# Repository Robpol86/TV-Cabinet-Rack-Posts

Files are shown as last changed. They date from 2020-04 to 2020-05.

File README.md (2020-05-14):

# TV Cabinet Rack Posts

3D printable rack posts with square holes for a Majestic EX 70-inch TV stand (Standout Designs).

* Cabinet dimensions (mm): **500** (W) x **460** (H) x **538** (D)
* Holes front offset: **112**
* Holes rear offset: **102**
* Top corner clearance with screw: **4.95**
* Door width: **20**
* Center of square hole distance: **465**

## Protocase Notes and Design Constraints

> TODO: Apply .05" fillets to corners.

### Material

> TODO: Increase to 3 mm.

304 Stainless Steel (A240 TP304 2B) 14 Gauge (**1.981 mm**)

### Colors

[Proto-Stock Matt Black, Low Gloss, Smooth Hybrid](https://www.protocase.com/img/products/mcf/powdercoat/matte-black-proto-stock.jpg)

### Bend Radius

https://www.protocase.com/resources/bend-radius.php

Category        |           Thickness | Minimum Bend | Bend Radius
--------------- | ------------------: | ------------:| ----------:
Stainless Steel | 14 Gauge (1.981 mm) |      6.98 mm |      1.9 mm

### K-Factor

> TODO: Derive k-factor from changed bend radius in eDrawing file sent by Protocase for v0.1.

* **0.440**

## Cura Settings

This is for a **Monoprice Maker Select 3D Printer v2** configured as a **Prusa i3** printer in Cura.

* Profile: **0.2**
* Infill: **20%**
* Infill Pattern: **Octet**
* Build Plate Adhesion: **Skirt**
* Skirt Distance: **6 mm**
* Support Placement: **Touching Buildplate**
* Support Overhang Angle: **50**
* Support Horizontal Expansion: **2**
* *Add support blocker to the rack holes*

## Planned Use

This section is to determine if the depth of the rack is sufficient in the short term.

   U | Current      | Future L      | Future R
---: | ------------ | ------------- | -------------
   1 | Patch Panel  | Patch Panel   | Patch Panel
   2 | Switch       | Switch        | Switch
   3 |              | pfSense + RPi | pfSense + RPi
   4 |              | SAN + Worker  | SAN + Worker
   5 |              | SAN + Worker  | SAN + Worker
   6 | pfSense + FS |               | GPU + Worker
   7 | pfSense + FS |               | GPU + Worker
   8 | Drawer       | Drawer        |
   9 | UPS          | UPS           | UPS
  10 | UPS          | UPS           | UPS

### Depths

* Posts (inner): **461 mm**
* Protocase Rails (C2907-18): **457 mm**
* Travla Rails: *2 inches too long, will sit on shelf*
* Drawer: **348 mm**
* UPS: *No depth because the rails won't fit. Will sit on the bottom.*

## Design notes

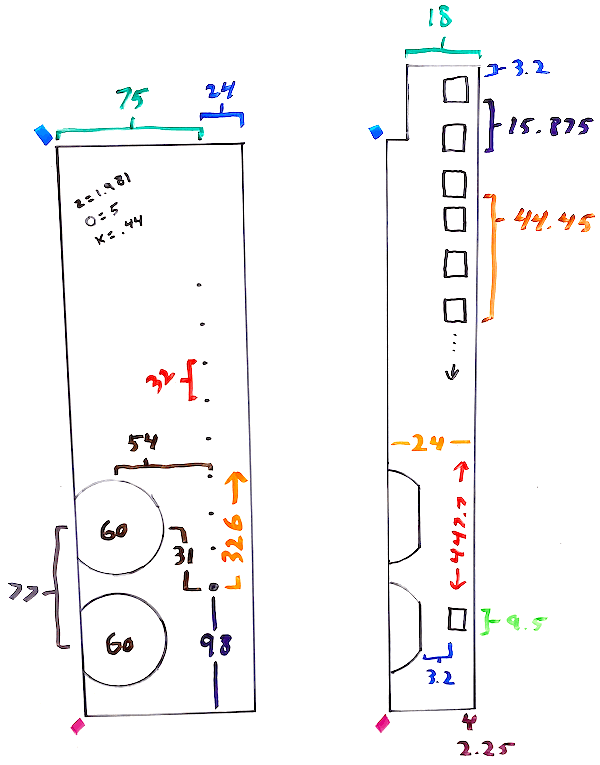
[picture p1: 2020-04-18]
blueprint.gif

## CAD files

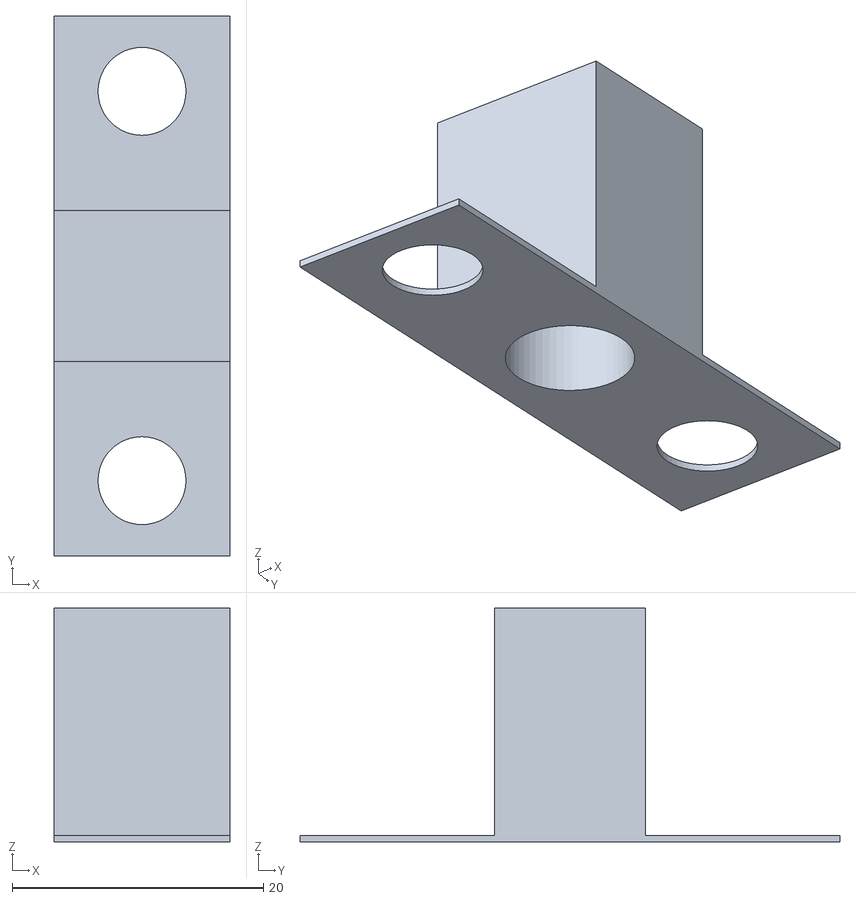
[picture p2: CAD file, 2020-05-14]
TV Cabinet Door Stop.stl
14.0 x 43.0 x 18.6

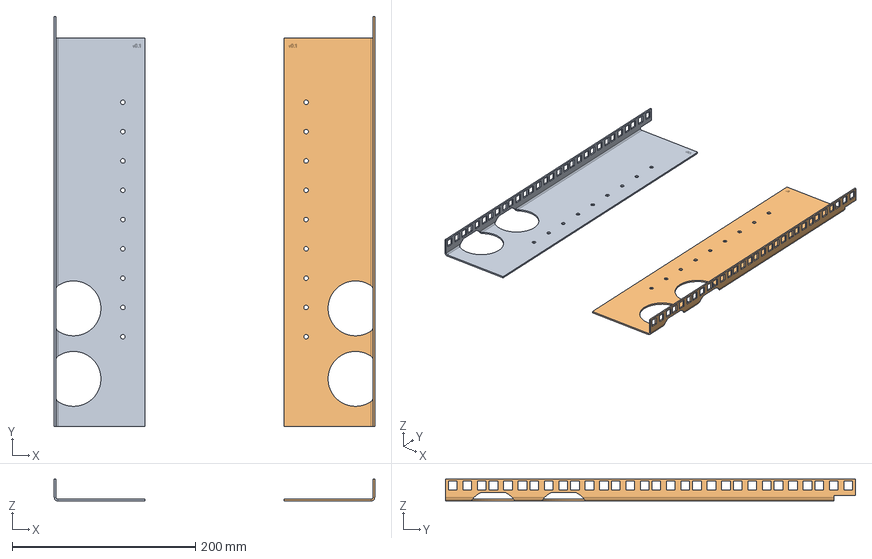
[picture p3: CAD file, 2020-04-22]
TV Cabinet Rack Posts.step
350.0 x 447.7 x 24.0 mm

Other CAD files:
TV Cabinet Door Stop.f3d
TV Cabinet Rack Posts.f3d

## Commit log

2020-03-29 First prototype: three holes
    Just a rectangle with three holes and empty middle sections to speed up
    printing. Reaches to the top of the cabinet, but it's a bit too tight.
    By the door on the left cabinet it's too close to the metal L 90-deg
    angle thing.
    [TV Cabinet Rack Posts.f3d, TV Cabinet Rack Posts.stl]
2020-03-29 Add hump and red reduce by 1 mm.
    Added one hump and reduced height by 1mm and front side by 1 mm.
    [TV Cabinet Rack Posts.f3d, TV Cabinet Rack Posts.stl]
2020-03-29 Added second hump.
    Also narrowed the top pillar again.
    [TV Cabinet Rack Posts.stl]
2020-03-30 From scratch: full height chopped
    Started over. New model is the full height of the cabinet, not just the
    top section. Full height model has been cut into three pieces and
    positioned so they all fit in my 200x200 3D printer.
    [TV Cabinet Rack Posts.f3d, TV Cabinet Rack Posts.stl]
2020-04-01 Adding square holes to the rear side for now.
    No adjustments to front side yet, just adding holes.
    [TV Cabinet Rack Posts.f3d, TV Cabinet Rack Posts.stl]
2020-04-08 Prototypes for one post, three dimensional.
    Draft of one of the rack posts, complete. Have yet to learn about
    tolerances and clearances for when this is sent to a metal shop and
    produced with 2mm thick bent steel.
    Other side can just be mirrored, verified it fits right.
    No rear posts yet.
    Patch panel mounted no problem to bottom of 10 U's.
    No screw indentations or threads or bracing beams yet.
    [TV Cabinet Rack Posts.f3d, TV Cabinet Rack Posts.stl]
2020-04-10 One model for front and back.
    Just need to mirror model to get all four posts. Cabinet holes perfectly
    aligned.
    [TV Cabinet Rack Posts.f3d, TV Cabinet Rack Posts.stl]
2020-04-14 Adding bottom bracing and TODOs.
    Refactored with thickness equal to what's available for stainless steel
    from Protocase, slightly under 2 mm.
    Also adding cabinet dimensions to README.
    [TV Cabinet Rack Posts.f3d, TV Cabinet Rack Posts.stl]
2020-04-16 No feet, no bracing.
    Redesigned again. Will rely on holes on solid wood cabinet wall.
    No bracing needed anymore, removing them from model.
    Resolved all TODOs.
    [TV Cabinet Rack Posts.f3d, TV Cabinet Rack Posts.stl]
2020-04-18 Refactored for Sheet Metal
    Using Sheet Metal feature in Fusion 360. Keeping bend radius in mind
    with big holes. Sketching them at the end in the unfolded view.
    Settled on a specific stainless steel offered by Protocase.
    [TV Cabinet Rack Posts.f3d, TV Cabinet Rack Posts.stl]
2020-04-19 Stampped version to both models.
    Using v0.1 for the first fabrication. Haven't yet contacted the company
    so model may change based on their feedback. Will keep the version until
    the first fabrication.
    [TV Cabinet Rack Posts.f3d]
2020-04-19 Remove TODOs.
    Forgot in the last commit. No room for silkscreen, especially with the
    holes on the bottom. Marking is already in the model.
2020-04-22 Sent email, attached the STEP file.
    Email was:
    to: info@protocase.com
    date: Apr 22, 2020, 2:30 PM
    subject: Inquiring about a quote for custom designed server rack
    posts
    Hello, I'm designing a custom server rack that fits inside of my TV
    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
    [TV Cabinet Rack Posts.step]
2020-04-30 Saving notes from Protocase.
    Now that v0.1 is in production there's nothing else to change unless I
    have to adjust the models for another prototype.
2020-05-04 Adding door fans holder.
    Positive air pressure ventilation on the front. Will look ugly, I may
    redesign it in the future to make it look nicer.
    [Door Fans Holder.f3d]
2020-05-05 Adding TODO.
    Now that I got a physical prototype everything worked out perfect except
    for the 5mm hole sizes and it's more than expected flimsyness.
    The hole problem is because the powdercoat slightly shrunk the hole
    diameter, but I worked around this by using a mallet to drive a peg
    through the hole. Ended up fitting snugly as I initially expected
    afterwards, so that problem is solved.
    However 2 mm of thickness is more flimsy than I thought. If The UPS's
    rails were shoter I would mount the UPS on the rack, and I would feel
    better if it were a bit thicker. I read somewhere that racks should be
    2mm to 3mm thick, so going with the low end was a small mistake. However
    since I wont be mounting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
2020-05-14 No door fan holder, add door stop.
    Not going forward with the door fans holder. Too ugly and no time to
    build a fan controller circuit. Instead I'll go with 5V fans in the rear
    connected to two different USB power adapters. No splicing or soldering
    needed. Similar setup to current 12V on 9V power adapter implementation.
    Adding door stop 3D model with disc magnet inside.
    [Door Fans Holder.f3d, TV Cabinet Door Stop.f3d, TV Cabinet Door Stop.stl]
